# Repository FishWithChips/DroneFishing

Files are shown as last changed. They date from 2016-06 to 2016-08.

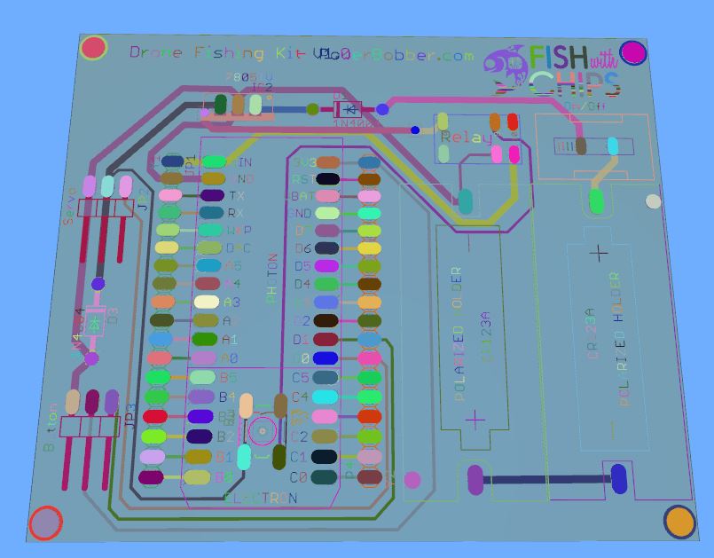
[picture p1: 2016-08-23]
Hardware/PCB/Gerber3D photo.JPG

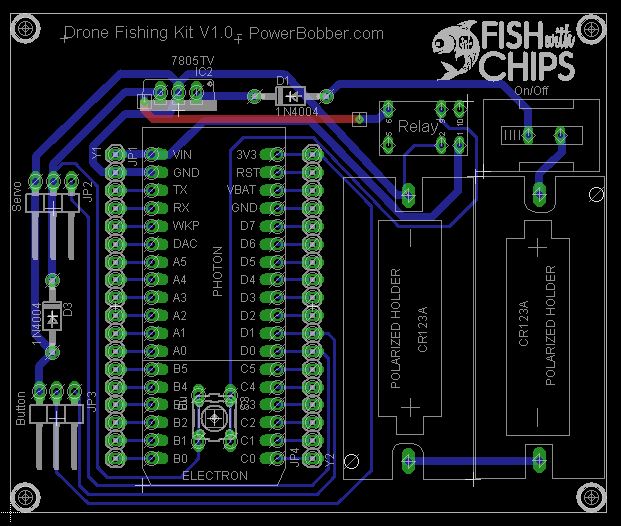
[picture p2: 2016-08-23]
Hardware/PCB/brd photo.JPG

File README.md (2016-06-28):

Drone Fishing

An open source repository for our Remote Control Drone Fishing Kit!

The Drone Fishing kit is a small battery powered device that you can connect to your drone.  
You then hook your fishing line from your fishing pole to the slider bar on the device.

Remotely connect to the device with wifi and then fly your drone out to the location you want to fish, 
Issue a single command and it will drop your bait into the water and your fishing.

Fly your drone home, or fly higher to watch your bait.  Don't scare away the fish!

Reel in your pole like normal, due to your extended cast you sure to catch a fish!
Just be careful and dont get your line tangled up somewhere!

We outline all the parts you need to put together your own drone fishing device!
Or you can buy our kit and assemble it yourself or order a fully assembled kit.

This is Fishing Awesome!

http://PowerBobber.com
http://DIYDroneFishing.com 

#DroneFishing

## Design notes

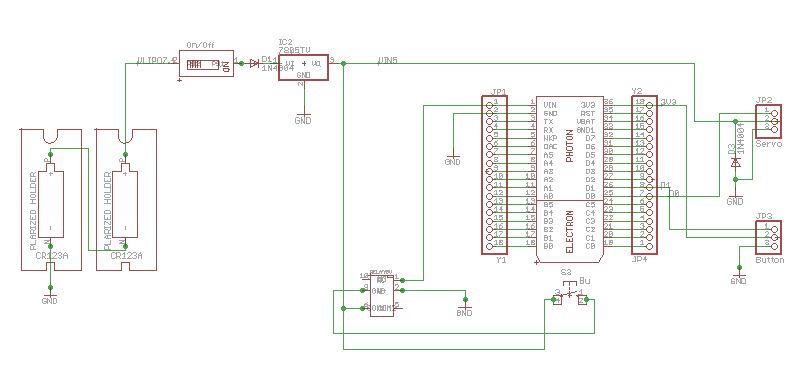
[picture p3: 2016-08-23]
Hardware/PCB/sch photo.JPG

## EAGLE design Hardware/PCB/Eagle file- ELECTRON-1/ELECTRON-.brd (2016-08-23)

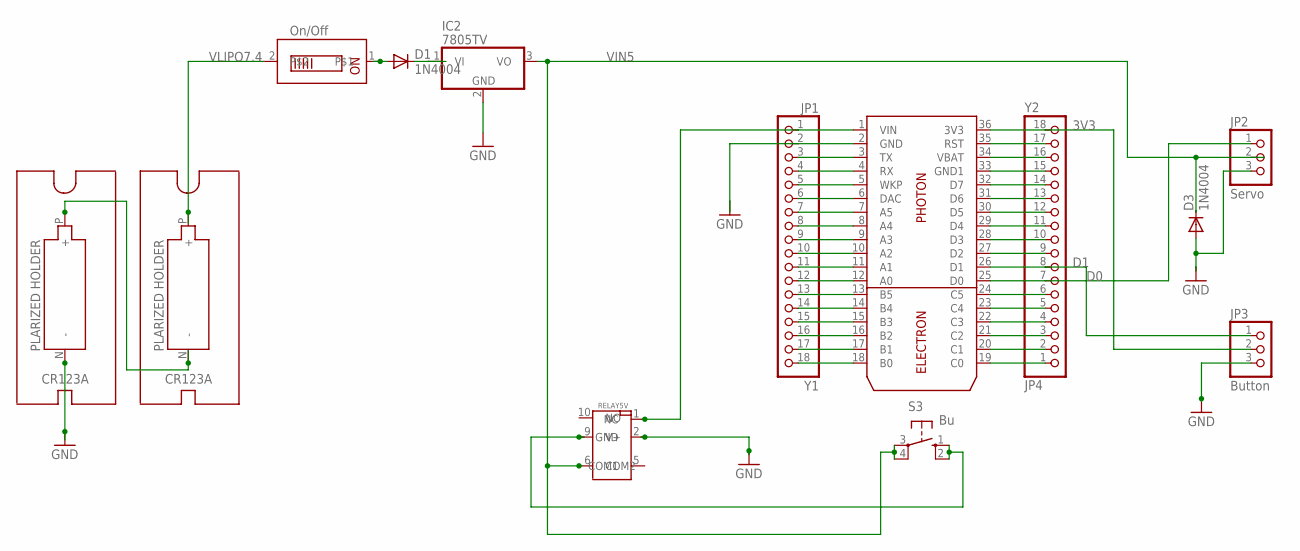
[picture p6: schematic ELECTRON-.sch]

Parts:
D1, D3: 1N4004; DO41-10
ELECTRON2: ELECTRON; ELECTRON-U260
IC2: 7805TV; TO220V
JP1: Y1; 1X18
JP2: Servo; 1X03/90
JP3: Button; 1X03/90
JP4: Y2; 1X18
S3: Bu; B3F-10XX
U$1, U$2: POLARIZEDHOLDER-CR123A; CRT123A
U$3: SWIDGET; GF-123-0054
U$4: RELAY5V; RELAY5V-F

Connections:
3V3: ELECTRON2.36 (3V3), JP3.2, JP4.18
D0: ELECTRON2.25 (D0), JP2.1, JP4.7
D1: ELECTRON2.26 (D1), JP3.1, JP4.8
GND: D3.A, ELECTRON2.2 (GND), IC2.2 (GND), JP1.2, JP2.3, JP3.3, U$1.N (-), U$4.2 (GND)
unnamed: S3.1 (S), S3.2 (S1), U$4.9 (V+)
unnamed: ELECTRON2.3 (TX), JP1.3
unnamed: D1.C, IC2.1 (VI)
unnamed: ELECTRON2.4 (RX), JP1.4
unnamed: ELECTRON2.33 (GND1), JP4.15
unnamed: ELECTRON2.5 (WKP), JP1.5
unnamed: U$1.P (+), U$2.N (-)
unnamed: ELECTRON2.6 (DAC), JP1.6
unnamed: ELECTRON2.35 (RST), JP4.17
unnamed: ELECTRON2.7 (A5), JP1.7
unnamed: ELECTRON2.34 (VBAT), JP4.16
unnamed: ELECTRON2.8 (A4), JP1.8
unnamed: ELECTRON2.9 (A3), JP1.9
unnamed: ELECTRON2.10 (A2), JP1.10
unnamed: ELECTRON2.32 (D7), JP4.14
unnamed: ELECTRON2.11 (A1), JP1.11
unnamed: ELECTRON2.31 (D6), JP4.13
unnamed: ELECTRON2.12 (A0), JP1.12
unnamed: ELECTRON2.13 (B5), JP1.13
unnamed: ELECTRON2.14 (B4), JP1.14
unnamed: ELECTRON2.15 (B3), JP1.15
unnamed: ELECTRON2.16 (B2), JP1.16
unnamed: ELECTRON2.17 (B1), JP1.17
unnamed: ELECTRON2.18 (B0), JP1.18
unnamed: ELECTRON2.30 (D5), JP4.12
unnamed: ELECTRON2.29 (D4), JP4.11
unnamed: ELECTRON2.28 (D3), JP4.10
unnamed: ELECTRON2.27 (D2), JP4.9
unnamed: ELECTRON2.24 (C5), JP4.6
unnamed: ELECTRON2.23 (C4), JP4.5
unnamed: ELECTRON2.22 (C3), JP4.4
unnamed: ELECTRON2.21 (C2), JP4.3
unnamed: ELECTRON2.20 (C1), JP4.2
unnamed: ELECTRON2.19 (C0), JP4.1
unnamed: D1.A, U$3.1
VIN5: D3.C, IC2.3 (VO), JP2.2, S3.3, S3.4 (P1), U$4.6 (COM2)
VLIPO7.4: U$2.P (+), U$3.2
VO5: ELECTRON2.1 (VIN), JP1.1, U$4.1 (NC)

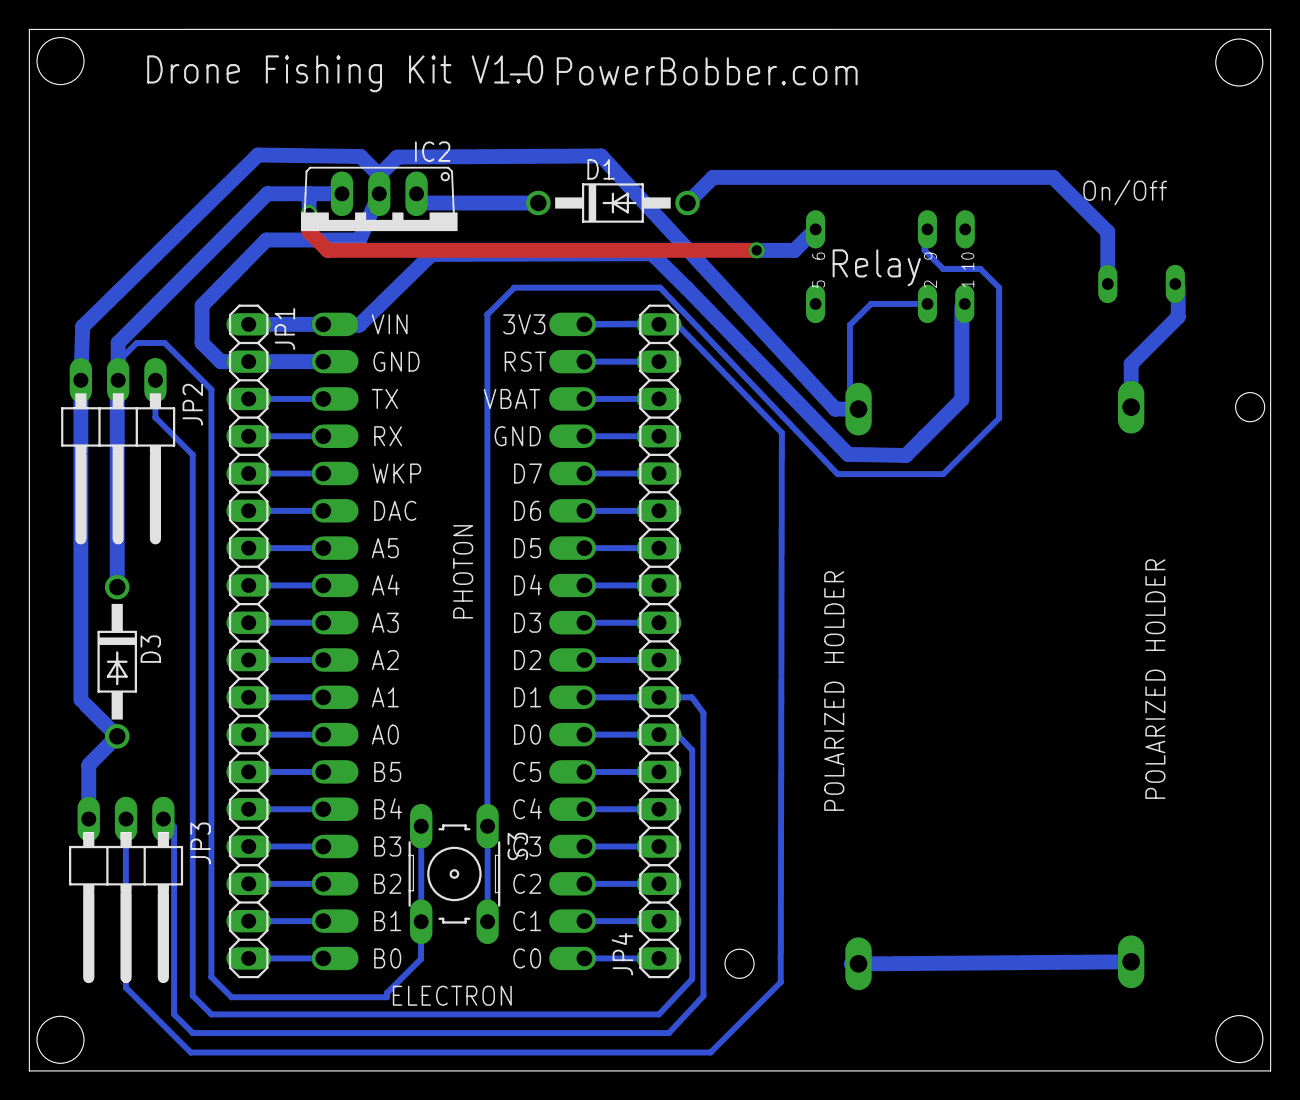
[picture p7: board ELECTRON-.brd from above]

Board: 2 copper layers, 84.5 x 70.9 mm, 13 parts (0 on the bottom side), 42 nets.

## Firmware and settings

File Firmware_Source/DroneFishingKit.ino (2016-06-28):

PRODUCT_ID(551); //Drone Fishing Kit
PRODUCT_VERSION(1);

// This #include statement was automatically added by the Particle IDE.
#include "Tinker-Servo/Tinker-Servo.h"

//
// COMPLEMENTARY API CALL
// POST /v1/devices/{DEVICE_ID}/{FUNCTION}
//
// # EXAMPLE REQUEST
// curl https://api.spark.io/v1/devices/0123456789abcdef01234567/servo \
//     -d access_token=1234123412341234123412341234123412341234 \
//     -d "args=180"
//----------------------------------------------------------------------------

Servo myservo;  // create servo object to control a servo
                // a maximum of eight servo objects can be created

const int buttonPin = D1;     // the number of the pushbutton pin
const int servoPin = D0;     // the number of the servo pin
const int ledPin = D7;     // the number of the LED pin

// variables will change:
int buttonState = 0;         // variable for reading the pushbutton status
int pos = 0;    // variable to store the servo position
bool remoteOverride = false;  // variable to tell the loop the command is being overridden remotely.

  STARTUP(WiFi.selectAntenna(ANT_INTERNAL)); // selects the CHIP antenna
  //STARTUP(WiFi.selectAntenna(ANT_EXTERNAL)); // selects the u.FL antenna
  
void setup()
{
  // attaches the servo on the A0 pin to the servo object
  myservo.attach(servoPin);
  
  pinMode(buttonPin, INPUT);
  pinMode(ledPin, OUTPUT);
  
  Particle.publish("Setup complete", buttonState);
  // turn on 20k pullup resistor
  //digitalWrite(buttonPin, HIGH);
  
  // register the Spark function
  Particle.function("servo", updateServo);
}

void loop()
{
  // do nothing
  // read the state of the pushbutton value:
  buttonState = digitalRead(buttonPin);

    if (!remoteOverride)
    {
        
      Particle.publish("Button state", buttonState);
      // check if the pushbutton is pressed.
      // if it is, the buttonState is HIGH:
      if (buttonState == HIGH) {
          
          if (pos != 150)
          {
                Particle.publish("Button on , moving servo", buttonState);
                pos = 150;
                myservo.write(pos);
                delay(1000);
          }
      } else {
        // turn LED off:
            if (pos != 30)
            {
                Particle.publish("Button off , resetting servo", pos);
                pos = 30;
                myservo.write(pos);
                delay(1000);
            }
      }
    }
}

//this function automagically gets called upon a matching POST request
int updateServo(String command)
{
    remoteOverride = true;
    
    // convert string to integer
    uint8_t pos = command.toInt();

      // process if integer is 0 - 180
      if(pos <= 180)
      {
        // tell servo to go to position in variable 'pos'
        myservo.write(pos);
    
        if(pos == 0) {remoteOverride= false;}
        
        // return an integer success code that can be processed by our app
        return 200;
      }
      else {
        // return an integer error code that can be processed by our app
        return -1;
      }
      
      
}

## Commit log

2016-06-28 Adding initial version of The DIY Drone Fishing Kit (DFK). This software accompanies the DFK hardware which the current version runs on a Particle Photon powered device. Get more info at http://power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
2016-08-23 Adding PCB files
    [ELECTRON-.brd, ELECTRON-.sch]
2016-09-06 Added Servo Start and End position to UI
